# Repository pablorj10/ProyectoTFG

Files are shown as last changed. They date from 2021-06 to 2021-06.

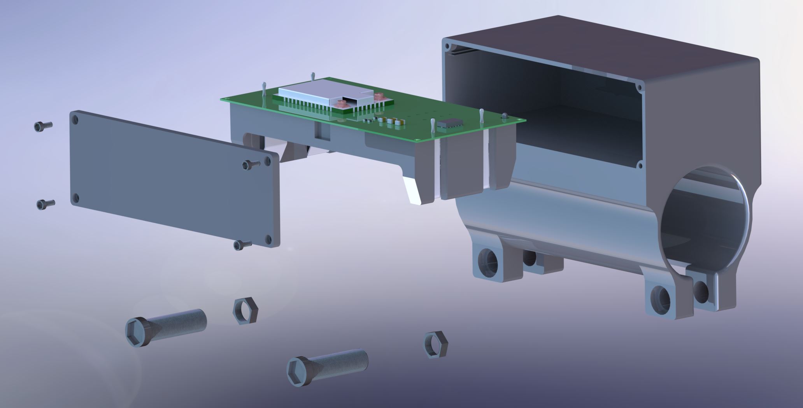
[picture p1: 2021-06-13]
SolidWork/Fotos/Captura2.JPG

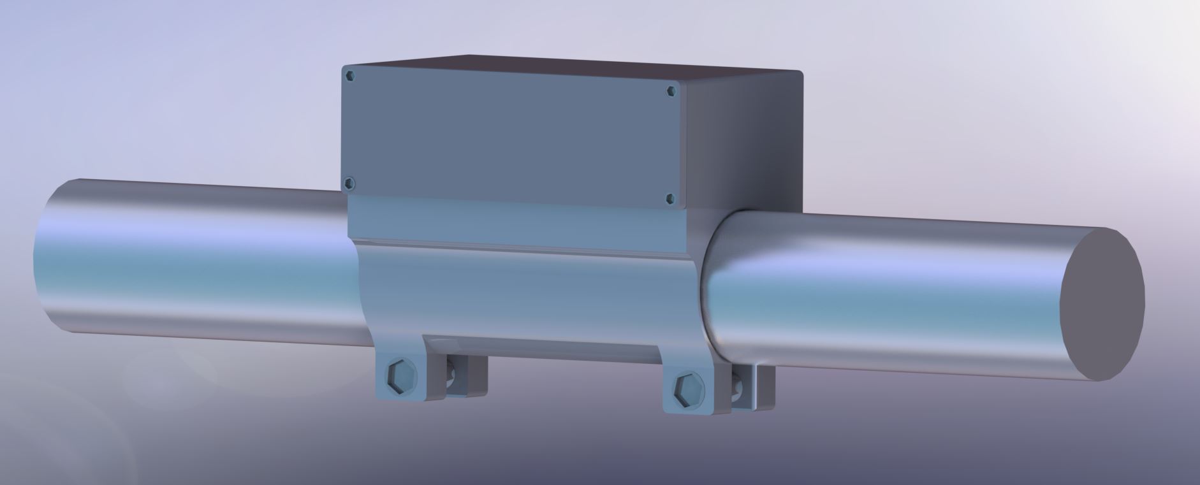
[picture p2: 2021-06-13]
SolidWork/Fotos/Captura3.JPG

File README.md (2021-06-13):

# ProyectoTFG
Repositorio donde se muestran todos los documentos para la elaboración del Trabajo de Fin de Grado de la carrera de Grado en Ingeniería Electrónica Industrial de la Universidad de Granada: Plataforma IoT para el seguimiento de la actividad deportiva en parques biosaludables elaborado por Pablo Rubio Jiménez.

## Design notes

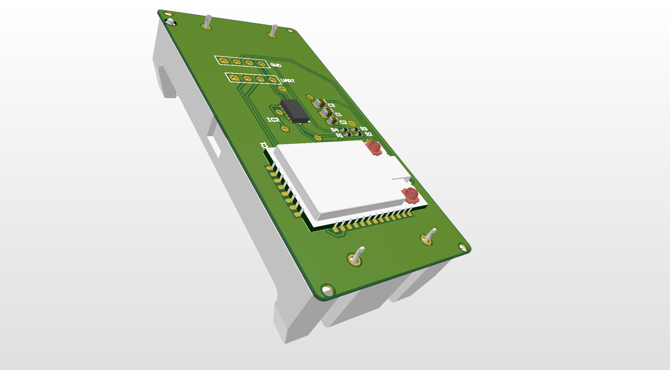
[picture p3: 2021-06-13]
Altium/TFG_Dispositivo/PCB_Dispositivo2.jpg

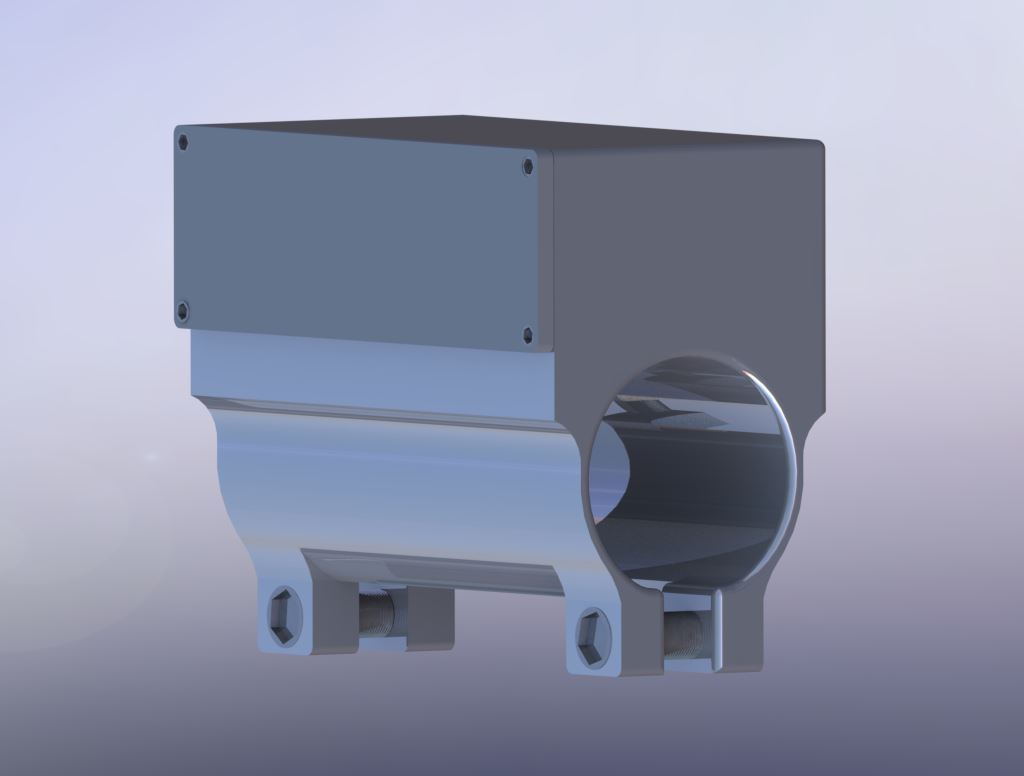
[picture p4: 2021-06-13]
SolidWork/Fotos/Captura1.JPG

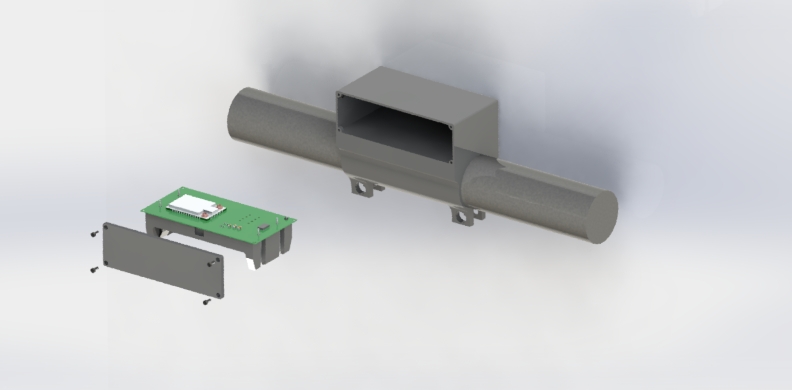
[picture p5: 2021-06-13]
SolidWork/Fotos/preview.JPG

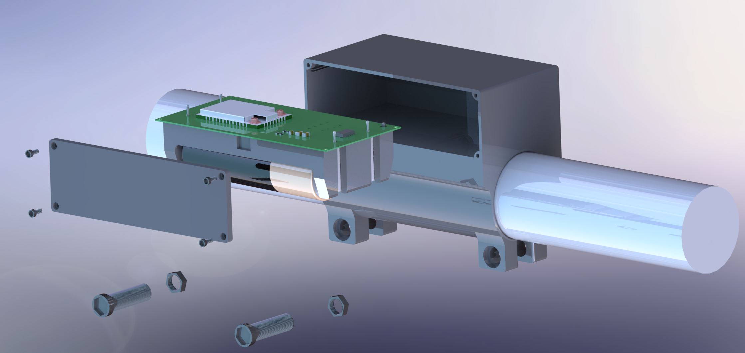
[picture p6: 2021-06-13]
SolidWork/Fotos/Captura5.JPG

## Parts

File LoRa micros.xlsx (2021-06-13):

TECNOLOGÍA LORA
Microcontrolador | Módulo LoRa | Microcontrolador | Medidas | Consumo | Alimentación | Frecuencia de transmisión | Memoria Flash | SRAM | EEPROM | Precio
Bastwan | RAK3244 | SAMD21 Cortex-M0 | 50,8 x 22,8 mm | 123,6 mA Máx. (Transmitiendo Tx), 13,6 mA Máx. (Recibiendo Rx), 860 nA (Sleep Mode) | USB (5V) o batería Li-Po | 862-1020 MHz | 256 KB | 32 KB | No | 29.90 €
MKR1300 Arduino | CMWX1ZZABZ | SAMD21 Cortex-M0 | 67,64 x 25 mm |  | USB (5V) o Baterías 2x AA o AAA | 433/868/915 MHz | 256 KB | 32 KB | No | 24.50 €
MKR1310 Arduino | CMWX1ZZABZ | SAMD21 Cortex-M0 | 67,64 x 25 mm | Consumo Medio de 104 uA | USB (5V) o baterías recargables Li-ion o Li-Po, con mínimo de 1024 mAh de capacidad | 433/868/915 MHz | 256 KB (CPU internal) y 2 MB (QSPI external) | 32 KB | No | 33.00 €
IoT Platzi ESP32 + Lora (Wifi, Bluetooth, LoRa) | SX1276 | ESP32 |  | 29-120 mA (transmitiendo), 0,2 uA (sleep mode),1,5 uA (IDLE) |  | 433/868/915 MHz |  |  |  | 35.00 €
ADAFRUIT FEATHER Mo RFM96/5 LoRa Radio | RFM95 | SAMD21 Cortex-M0 | 50,8 x 23 mm | 120 mA Máx. (Transmitiendo Tx), 40 mA Máx. (Recibiendo Rx), 0,3 mA (Sleep Mode) | USB (5V) o Batería de Polímero de Litio de 3,7V | 433/868/915 MHz | 256 KB | 32 KB | No | 36.95 €
A todos estos consumos, se les debe sumar el consumo propio de los demás elementos de la placa como resistencias, condensadores etc.
CONSUMO Microcontrolador | SAMD21 Cortex-M0
 | Activo |  | IDLE |  | StandBy
 | Min | 3.7 | Min | 1.3 | Min | 0.0034
 | Max | 4.7 | Max | 2.6 | Max | 0.104
 | Módulo LoRa |  |  |  | Simulación del consumo
 | Max. | 120
 | Min. | 70 |  | Horas | Personas | Consumo medio en la hora (mA)
 |  |  |  | 1:00:00 | 0 | 0.104 |  | Datos de las personas y las horas obtenidas del artículo: Chow H-w, Mowen AJ, Wu G-l. Who Is Using Outdoor Fitness Equipment and How? The Case of Xihu Park. International Journal of Environmental Research and Public Health. 2017; 14(4):448. https://doi.org/10.3390/ijerph14040448
 |  |  |  | 2:00:00 | 0 | 0.104
Suponiendo que el módulo de LoRa está activado durante 5 segundos, por cada persona que usa la máquina. El resto del tiempo está apagado. |  |  |  | 3:00:00 | 0 | 0.104
 |  |  |  | 4:00:00 | 0 | 0.104
 |  |  |  | 5:00:00 | 0 | 0.104
 |  |  |  | 6:00:00 | 0 | 0.104
 | Tiempo LoRa por persona (s) | 0 |  | 7:00:00 | 20 | 0.2316666667
 |  |  |  | 8:00:00 | 25 | 0.2635833333 |  | Batería (mAh) | 4000
Suponiendo que el microcontrolador está en modo activo durante 5 segundos, por cada persona que usa la máquina. El resto del tiempo está en modo standby. |  |  |  | 9:00:00 | 16 | 0.2061333333
 |  |  |  | 10:00:00 | 7 | 0.1486833333
 |  |  |  | 11:00:00 | 7 | 0.1486833333 |  | Duración Bateria (Años) | 3.239132827
 |  |  |  | 12:00:00 | 3 | 0.12315 |  | Meses | 38.86959393
 | Tiempo MCU por persona (s) | 5 |  | 13:00:00 | 2 | 0.1167666667 |  | Días | 1166.087818
 |  |  |  | 14:00:00 | 3 | 0.12315
 |  |  |  | 15:00:00 | 9 | 0.16145
 |  |  |  | 16:00:00 | 14 | 0.1933666667
 |  |  |  | 17:00:00 | 16 | 0.2061333333
 |  |  |  | 18:00:00 | 4 | 0.1295333333
 |  |  |  | 19:00:00 | 6 | 0.1423
 |  |  |  | 20:00:00 | 7 | 0.1486833333
 |  |  |  | 21:00:00 | 0 | 0.104
 |  |  |  | 22:00:00 | 0 | 0.104
 |  |  |  | 23:00:00 | 0 | 0.104
 |  |  |  | 0:00:00 | 0 | 0.104
 |  |  |  |  | Consumo Medio (mA) | 0.1409701389

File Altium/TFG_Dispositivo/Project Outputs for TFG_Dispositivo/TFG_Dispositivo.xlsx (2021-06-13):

 | Bill of Materials
 |  |  |  |  |  |  | 2175 Salk Avenue
 | Project Title: | Bill of Materials for BOM Document [TFG_Dispositivo.BomDoc] |  |  |  |  | Suite 200
 | Project File Name: | TFG_Dispositivo.PrjPcb |  |  |  |  | Carlsbad, CA 92008
 | Assembly Variant: | None |  |  |  |  | USA
Part Number | Description | Designator | Manufacture | Manufacture Part Number | Supplier | Supplier Part Number | Supplier Unit Price | Quantity
C0805X104M5RACTU | Capacitor | C1, C3 | KEMET | C0603C104K5RACTU | Digi-Key | 399-5089-1-ND | $0.12 | 2
0603ZD106KAT2A | Capacitor | C2 | KEMET | C1210C106Z4VACTU | Digi-Key | 399-1272-6-ND | $0.57 | 1
RAK4600 | Integrated Circuit | IC1 | RAKWireless | - | RAKWireless | - | $9.70 | 1
ADXL345BCCZ-RL | Integrated Circuit | IC2 | Analog Devices | ADXL345BCCZ-RL7 |  |  |  | 1
Header 4 | Header, 4-Pin | P1, P2 | Wurth Electronics | 61300411121 | Digi-Key | 732-5317-ND | $0.18 | 2
CPF0402B10KE | Resistor | R1, R2, R3, R4 | Vishay | CRCW0603-10K0FKEA | Digi-Key | 541-10.0KHCT-ND | $0.04 | 4
1013 | Undefined or Miscellaneous | U1 | Keystone Electronics | 1013 | Digi-Key | 36-1013-ND | $4.64 | 1
 |  |  |  |  |  |  | $15.25 | 12
Approved |  | Notes

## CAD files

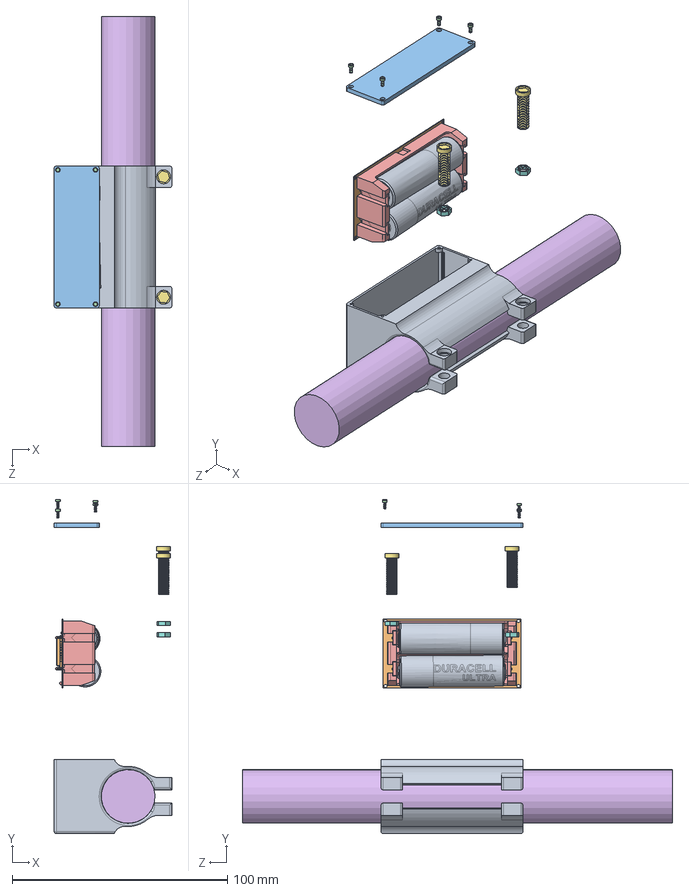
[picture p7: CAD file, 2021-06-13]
SolidWork/ENSAMBLAJE/Ensamblaje.SLDASM
54.8 x 155.4 x 200.0 mm
Pieza_Delantera
PCB_Dispositivo
Pieza_Tapadera
Pieza_Tornillo_Peque x 4
User Library-1013-1
Pieza_tornillo_grande x 2
Pieza_tuerca x 2
User Library-duracell ultra aa 1_5v mx 1500 lr6 x 2

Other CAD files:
Altium/TFG_Dispositivo/Pad RAK4600-23(29.2mm,13.75mm) on Top Layer-1.SLDASM
SolidWork/NetIC2_7.SLDASM
Altium/TFG_Dispositivo/TX.SLDASM
Altium/TFG_Dispositivo/Pad RAK4600-23(29.2mm,13.75mm) on Top Layer.SLDASM
SolidWork/Track (19.975mm,29.725mm)(20.3mm,29.4mm) on Top Layer.SLDASM
SolidWork/Track (22.2mm,53.3mm)(22.2mm,55.903mm) on Top Layer-1.SLDASM
SolidWork/Track (10.2mm,37.8mm)(10.2mm,53.1mm) on Top Layer-1.SLDASM
SolidWork/Pad ADXL345-6(19mm,58.097mm) on Top Layer.SLDASM
SolidWork/Track (18.353mm,49.947mm)(18.353mm,56.749mm) on Top Layer.SLDASM
SolidWork/Pad RAK4600-15(18.725mm,8.691mm) on Top Layer.SLDASM
SolidWork/Track (10.2mm,53.1mm)(17.9mm,60.8mm) on Top Layer.SLDASM
SolidWork/Pad RAK4600-36(24.975mm,31.391mm) on Top Layer.SLDASM
SolidWork/Polygon Region (0 hole(s)) Top Layer-2.SLDASM
SolidWork/Pad C1-2(27.19mm,46mm) on Top Layer-1.SLDASM
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

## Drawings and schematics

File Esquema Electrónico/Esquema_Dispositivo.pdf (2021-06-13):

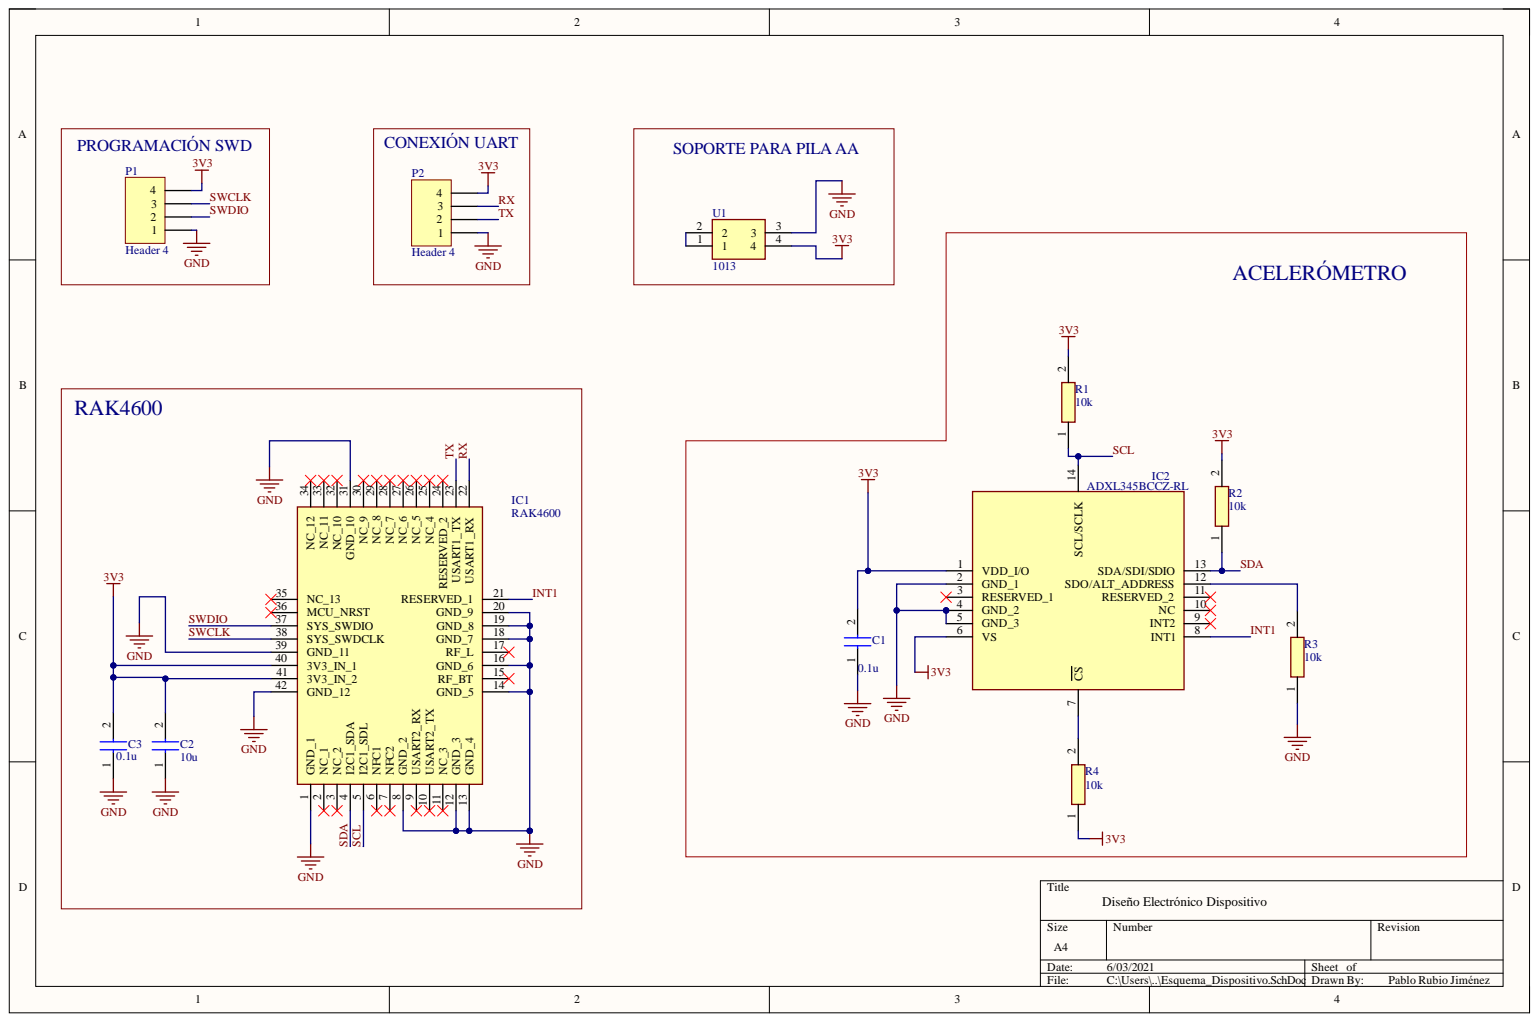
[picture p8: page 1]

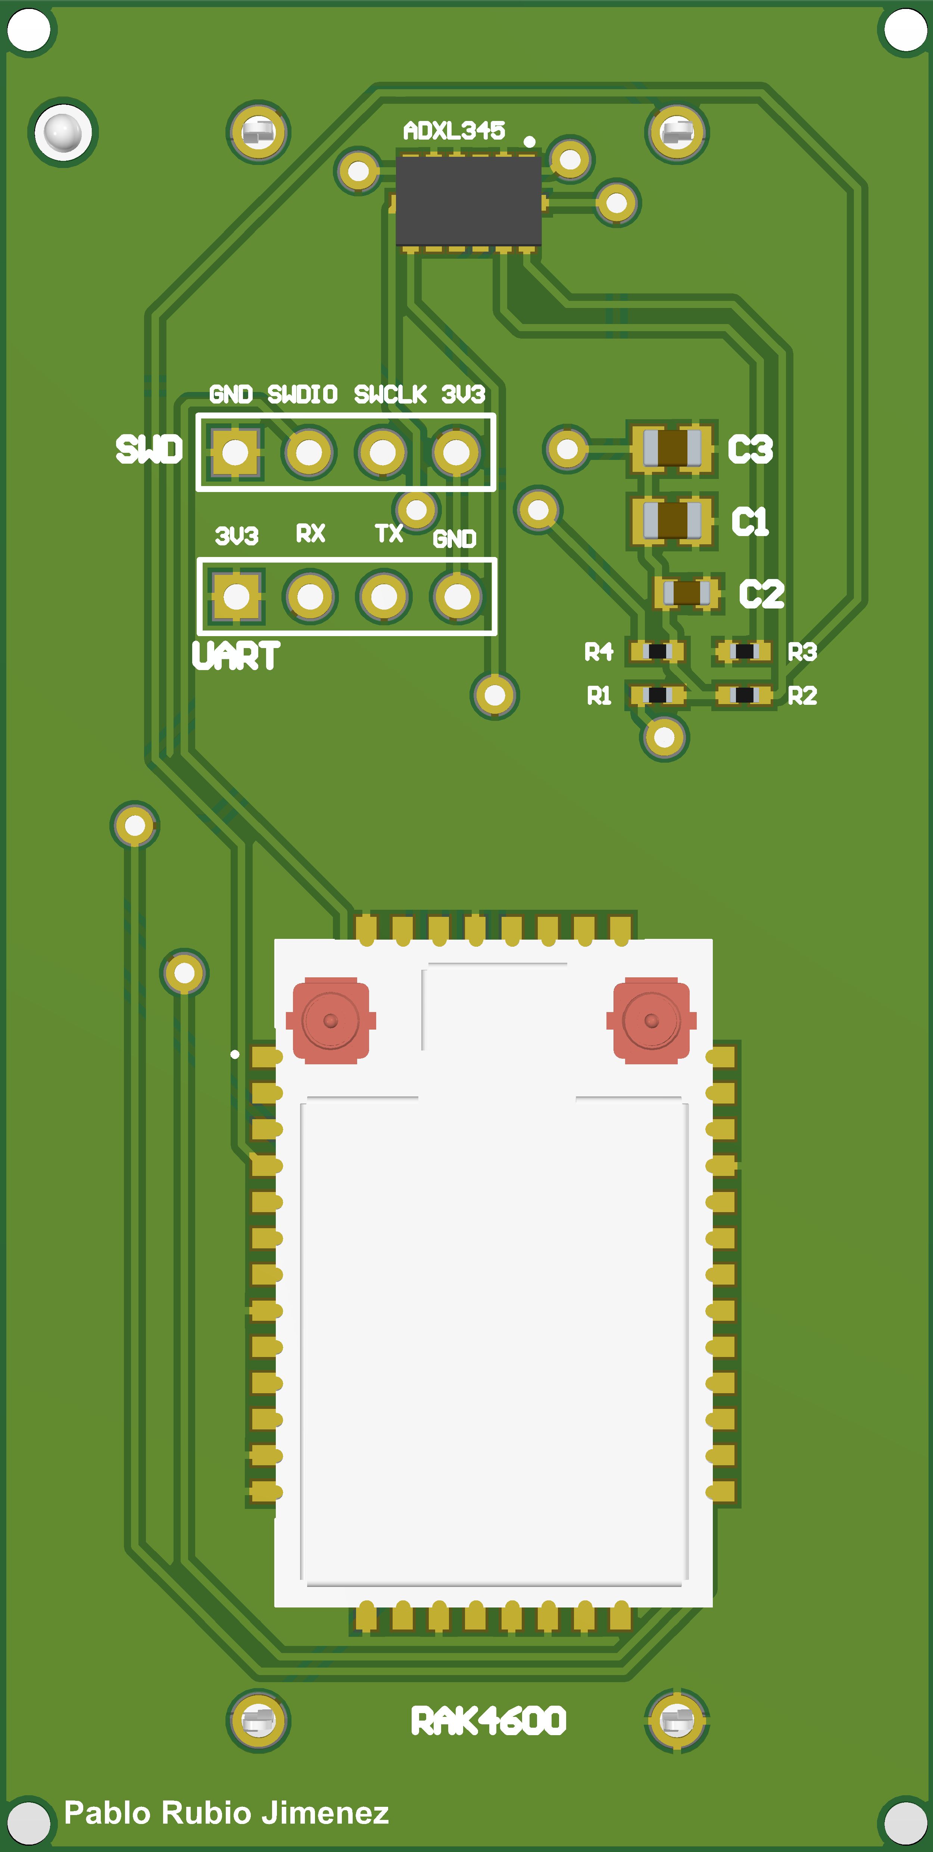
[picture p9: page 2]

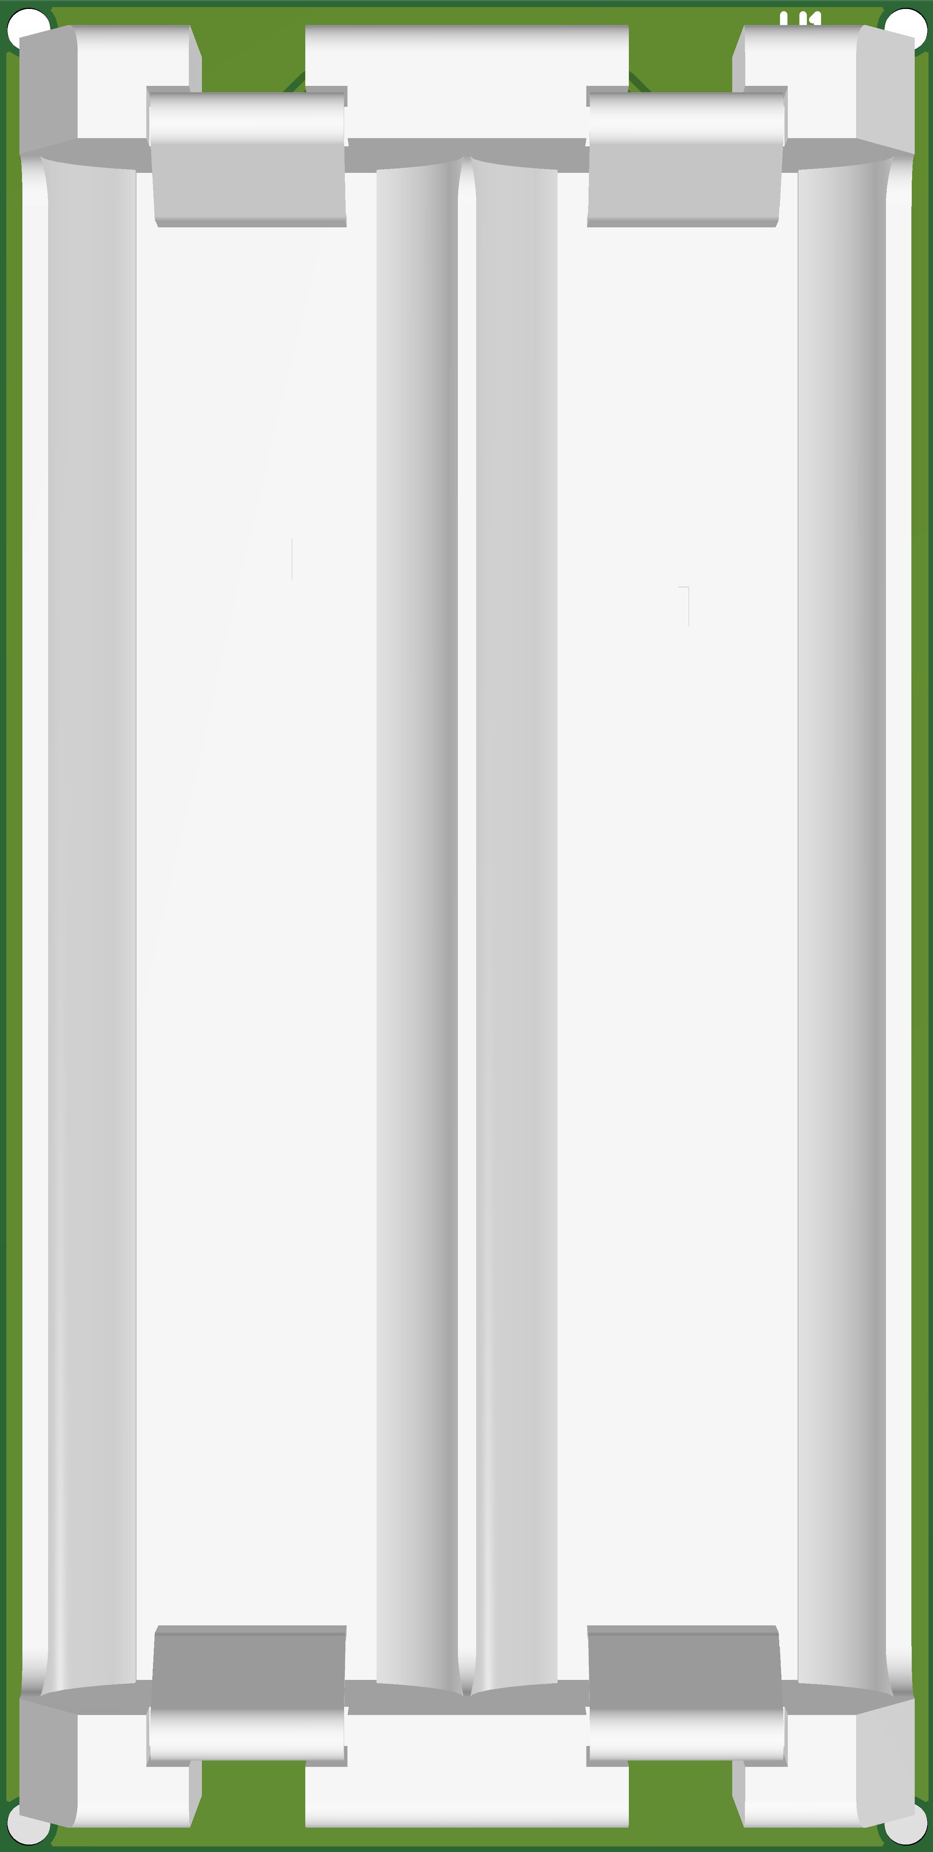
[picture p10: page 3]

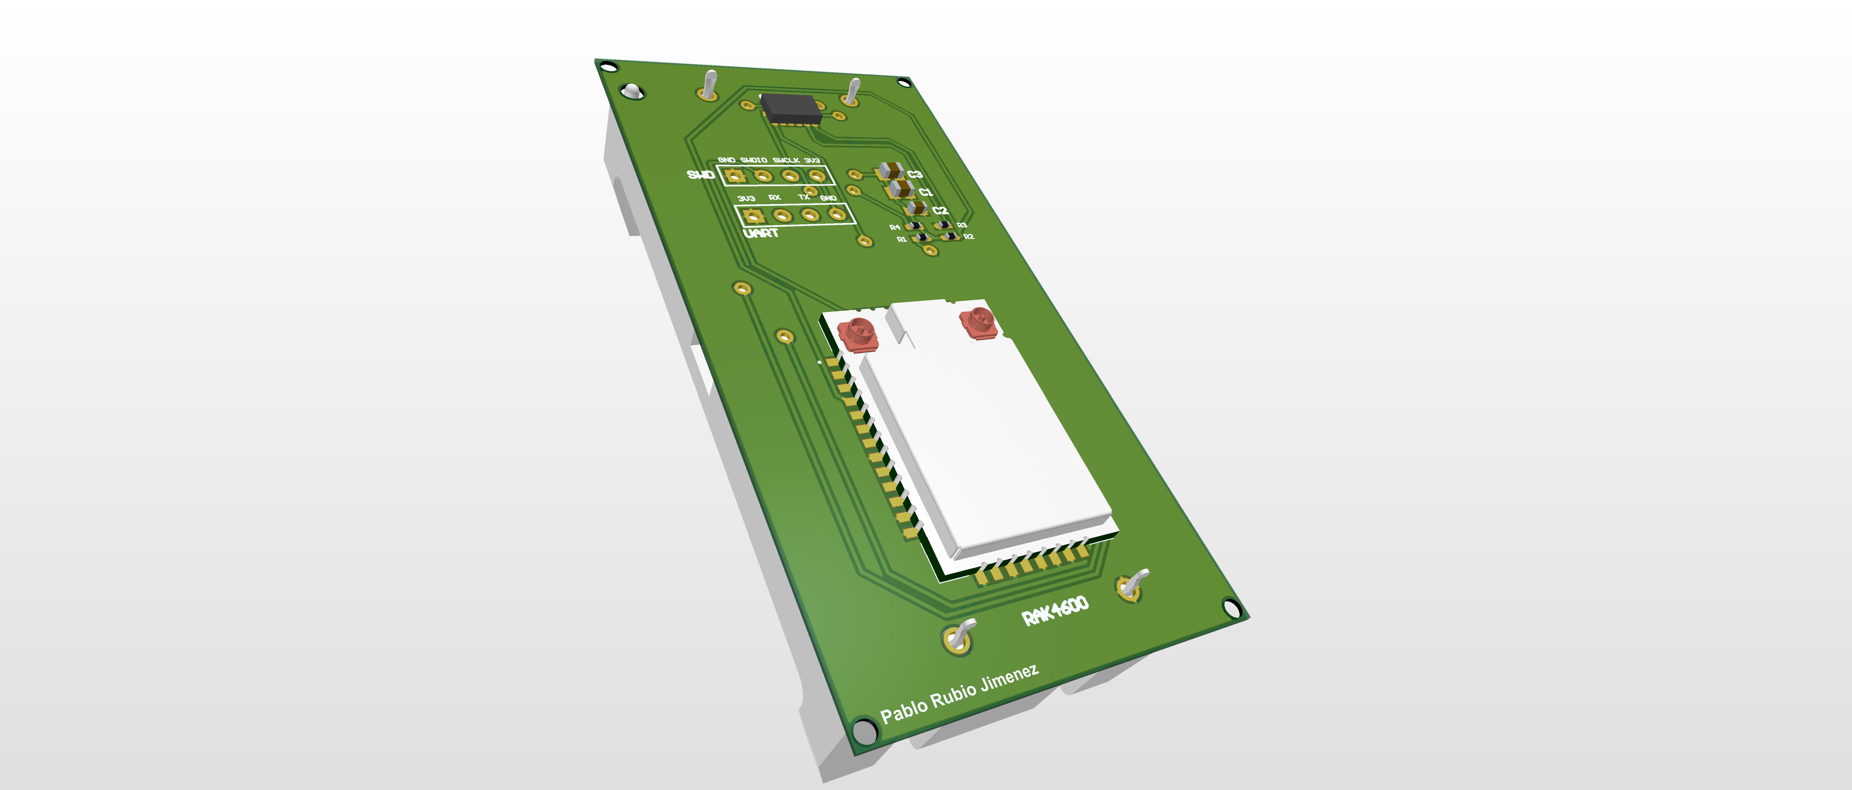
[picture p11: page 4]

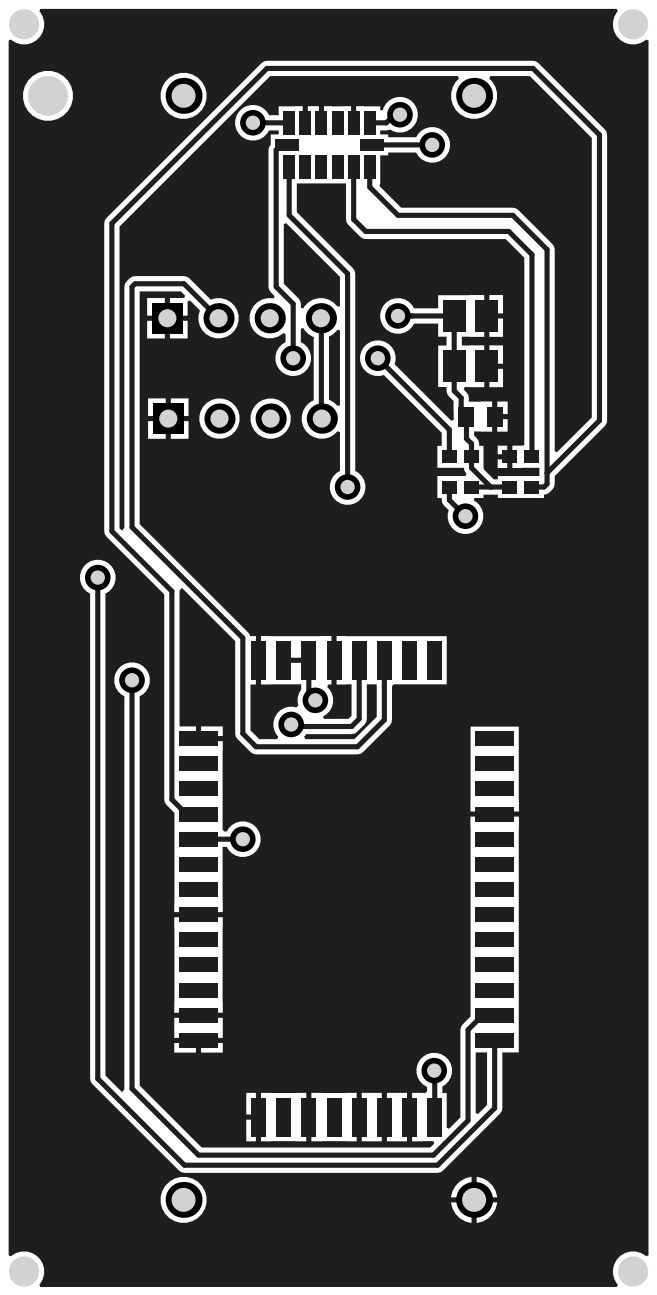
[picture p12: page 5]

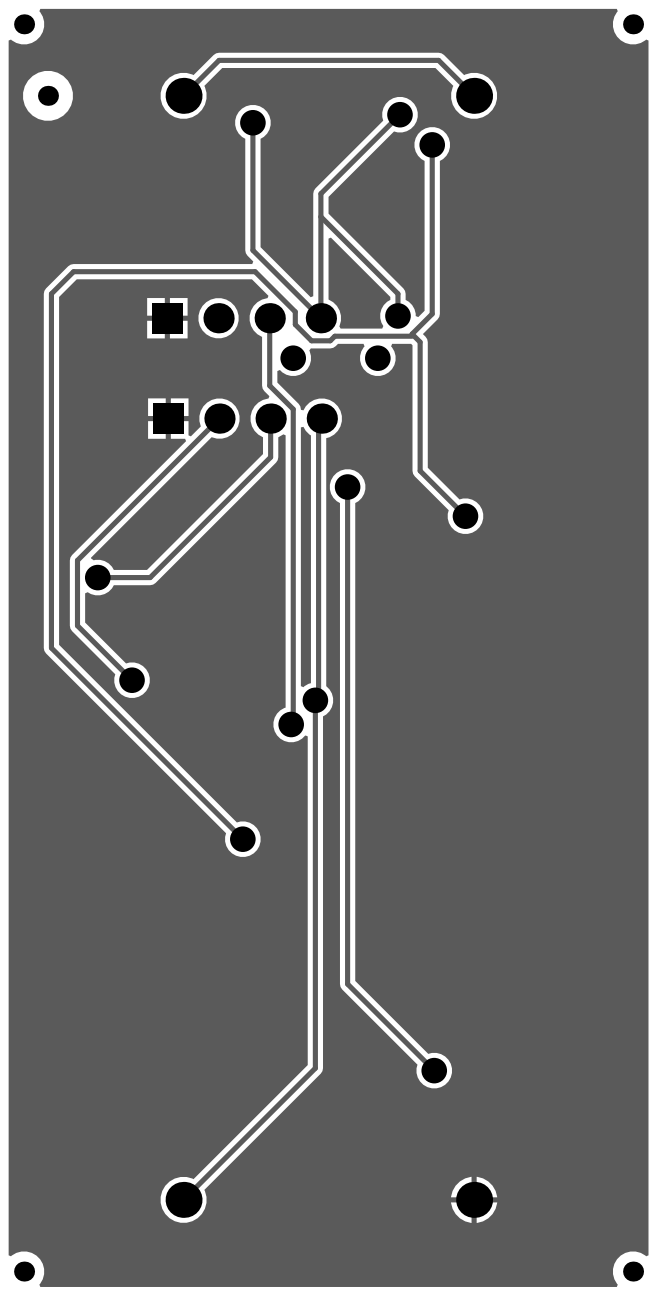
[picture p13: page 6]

# Bill of Materials

### 2175 Salk Avenue

Project Title: Bill of Materials for BOM Document [TFG_Dispositivo.BomDoc] | Suite 200
Project File Name: TFG_Dispositivo.PrjPcb | Carlsbad, CA 92008
Assembly Variant: None | USA
Part Number | Description | Designator | Manufacture | Manufacture Part Number | Supplier | Supplier Part Number | Supplier Unit Price | Quantity
C0805X104M5RACTCapacitor | | C1, C3 | KEMET | C0603C104K5RACTU | Digi-Key | 399-5089-1-ND | $0.12 | 2
0603ZD106KAT2ACapacitor | | C2 | KEMET | C1210C106Z4VACTU | Digi-Key | 399-1272-6-ND | $0.57 | 1
RAK4600 | Integrated Circuit | IC1 | RAKWireless | - | RAKWireless | - | $9.70 | 1
ADXL345BCCZ-RL Integrated Circuit | | IC2 | Analog Devices | ADXL345BCCZ-RL7 | Mouser | 584-ADXL345BCCZ-R7 | $6.23 | 1
Header 4 | Header, 4-Pin | P1, P2 | Wurth Electronics | 61300411121 | Digi-Key | 732-5317-ND | $0.18 | 2
CPF0402B10KE | Resistor | R1, R2, R3, R4 | Vishay | CRCW060310K0FKEA | Digi-Key | 541-10.0KHCT-ND | $0.04 | 4
1013 | Undefined or Miscellaneous | U1 | Keystone Electronics | 1013 | Digi-Key | 36-1013-ND | $4.64 | 1
| $21.48 12
Approved | Notes

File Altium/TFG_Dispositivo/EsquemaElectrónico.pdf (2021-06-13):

# 3V3 3V3 SDA

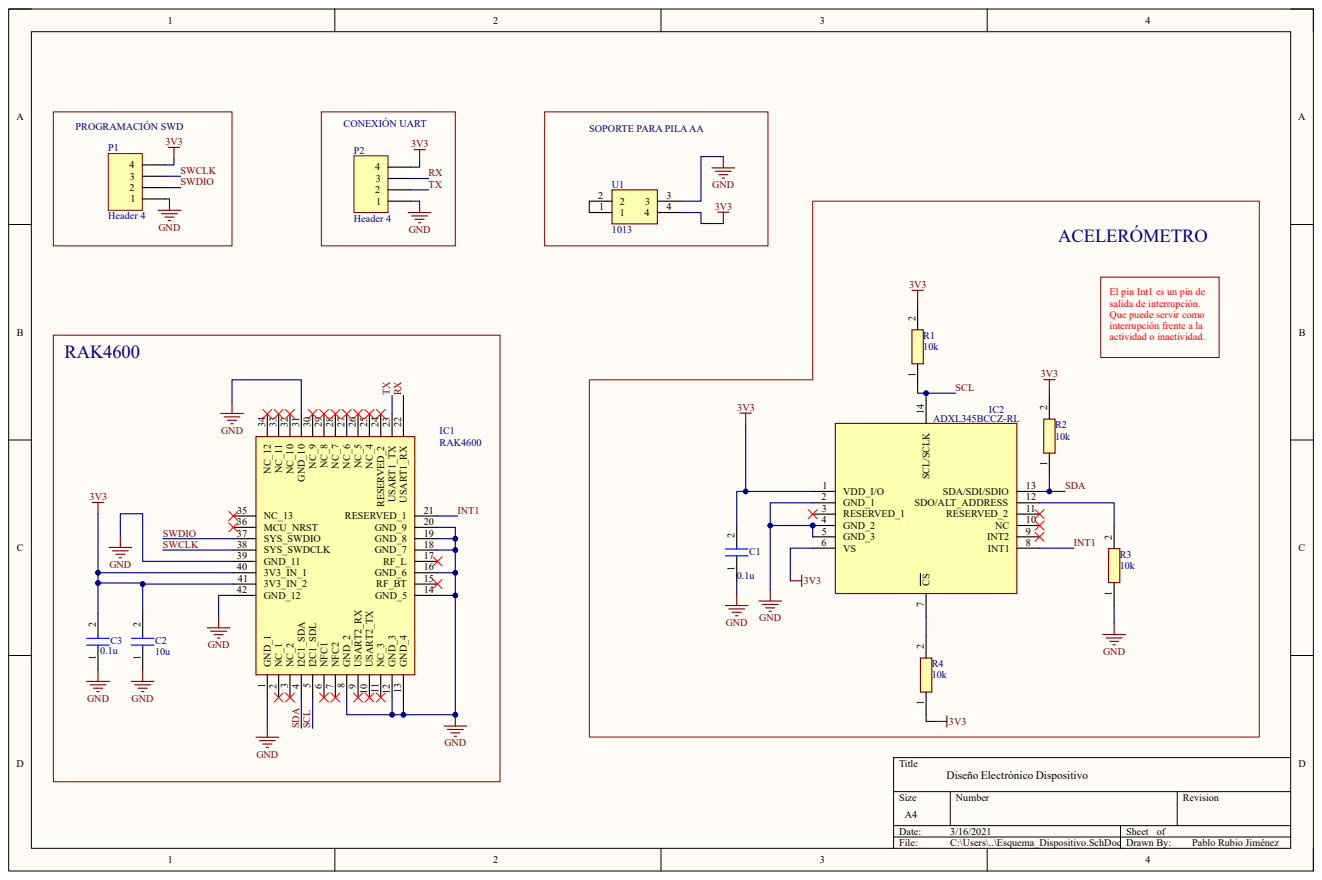
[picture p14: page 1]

SOPORTE PARA PILA AA

El pin Int1 es un pin de
salida de interrupción.
Que puede servir como
interrupción frente a la
actividad o inactividad.

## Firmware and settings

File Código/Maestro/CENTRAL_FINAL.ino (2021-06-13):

//LIBRERIAS
#include<Wire.h>                  
#include<ADXL345_WE.h>           
#include <Arduino.h>             
#include <bluefruit.h>            
#include <Adafruit_LittleFS.h>    
#include <InternalFileSystem.h>   
#include <lmic.h>                
#include <hal/hal.h>              
#include <SPI.h>                 
#include "NRF52TimerInterrupt.h"
#include "NRF52_ISR_Timer.h"
#include <stdlib.h>

/////VARIABLES E INSTANCIAS ///////
#define ADXL345_I2CADDR 0x53                                         
#define TIMER_INTERRUPT_DEBUG                0
#define _TIMERINTERRUPT_LOG_LEVEL_           0
#define PININT1 14
#define PINLED 17
NRF52Timer ITimer0 (NRF_TIMER_1);
NRF52_ISR_Timer  ISR_Timer0;

NRF52Timer ITimer1 (NRF_TIMER_3);
NRF52_ISR_Timer  ISR_Timer1;

ADXL345_WE myAcc(ADXL345_I2CADDR);

unsigned long temporizador_predefinido = 10;
volatile uint32_t temporizador; //SEGUNDOS
volatile uint32_t temporizador_variable;
unsigned long tiempo_reinicio = 30;
volatile uint32_t contador_reinicio = 0;
unsigned long numero_reinicio;
volatile uint8_t tiempo_espera = 20; //Tiempo en el que estara el dispositivo buscando nodos para configurarlos. 
unsigned long tiempo;

volatile uint8_t estado = 1;
typedef struct
{
  char name[16+1];
  uint16_t conn_handle;
  BLEClientUart clientUart;
}prph_info_t;

prph_info_t prphs[3];

volatile bool power = true;
int cont = 0;
volatile int posicion = 0;
uint8_t datos = 0;
unsigned long tiempoinicio;
unsigned long tiempofin;

void registro_dato();


SoftwareTimer blinkTimer;

volatile bool parar_lorawan = false;
volatile bool parar_ble = false;
volatile bool salir_estado5 = false;
volatile bool salir_ble1 = false;
volatile bool salir_lorawan1 = false;
volatile bool reinicio = false;





String datoscentral = "Central";
char datos1[100];
char datos2[100];
char datos3[100];
char datos4[100];
volatile uint8_t contador = 0;

volatile uint8_t tiempo_inactividad = 4;
static const u1_t PROGMEM APPEUI[8]={0x3F,0x19,0x04,0xD0,0x7E,0xD5,0xB3,0x70};
void os_getArtEui (u1_t* buf) { memcpy_P(buf, APPEUI, 8);}

// This should also be in little endian format, see above.
static const u1_t PROGMEM DEVEUI[8]={0x3E,0x4A,0x75,0xFE,0xFF,0xA8,0xC5,0x60};
void os_getDevEui (u1_t* buf) { memcpy_P(buf, DEVEUI, 8);}

// This key should be in big endian format (or, since it is not really a
// number but a block of memory, endianness does not really apply). In
// practice, a key taken from ttnctl can be copied as-is.
static const u1_t PROGMEM APPKEY[16] = { 0xDC,0x20,0x25,0xE8,0xCA,0xD9,0x0E,0x4A,0xF7,0x96,0xB0,0x9E,0xC1,0x82,0x38,0x0E };
void os_getDevKey (u1_t* buf) {  memcpy_P(buf, APPKEY, 16);}

volatile uint32_t lora_count = 0;
static osjob_t sendjob;
char Datos_conf[50] = "Configuracion";

uint8_t N = 10;
int Q;

volatile uint8_t cont1 = 0;
volatile uint8_t variable = 0;
typedef enum {
  LORA_UNCONFIRMED,
  LORA_CONFIRMED  
};

const unsigned TX_INTERVAL = 10;

const lmic_pinmap lmic_pins = {
    .nss = 4,
    .rxtx = LMIC_UNUSED_PIN,
    .rst = LMIC_UNUSED_PIN,
    .dio = {27, 28, 29},
};









////////////////////////////////////////////////////////////////////////////////////////////////////////////////////////////////////////////////////////
////////////////////////////////////////////////////////////VARIABLE DINAMICOS////////////////////////////////////////////////////////////////////////
///////////////////////////////////////////////////////////////////////////////////////////////////////////////////////////////////////////////////////

int* datostiempo;
size_t counta;
size_t capacity;


void reinicio_datos()
{
  Serial.println("Valores reiniciados");
  datoscentral = "";
  datoscentral = "Central";
  datos = 0;
  cont = 0;
  posicion = 0;
  memset(datos2, 0, sizeof(datos2));
}

void convertir_datos()
{
  Serial.println("Datos convertidos");
  int datos_len = datoscentral.length() + 1;
  datoscentral.toCharArray(datos1, 100);
}


void CreateList(size_t _capacity)
{
  datostiempo = new int[_capacity];
  capacity = _capacity;
  counta = 0;
}

void AddItem(int item)
{
  ++counta;
  if(counta> capacity)
  {
    size_t newSize = capacity*2;
    resize(newSize);
  }
  datostiempo[counta -1] = item;
}
void RemoveTail()
{
  --counta;
}

void Trim()
{
  resize(counta);
  
}

void resize(size_t newCapacity)
{
  int* newList = new int[newCapacity];
  memmove(newList, datostiempo, counta * sizeof(int));
  delete[] datostiempo;
  capacity = newCapacity;
  datostiempo = newList;
}

void PrintList()
{
  Serial.print("Datos Tiempos: ");
  for (size_t index = 0; index < counta; index++)
  {
    Serial.print(datostiempo[index]);
    Serial.print(' ');
  }
  Serial.println();

}


/////////////////////////////////////////////////////////////////////////////////////////////////////////////////////////////////////////
/////////////////////////////////////////////////////////////TEMPORIZADOR///////////////////////////////////////////////////////////////////
///////////////////////////////////////////////////////////////////////////////////////////////////////////////////////////////////////////



void funcion_tempo(TimerHandle_t xTimerID)
{
    (void) xTimerID;
    Serial.println("TIEMPO----------------------------");
    salir_estado5 = true;
    estado = 6;
    Serial.println("Parar temporizador");
  
}
void tiempo_de_espera()
{
  parar_ble = true;
  estado = 3;
}
void temporizador_handler()
{
  if(estado == 2)
  {
    ISR_Timer1.run();
    ISR_Timer1.setTimeout(tiempo_espera*1000, tiempo_de_espera);
  }
  if(estado == 4)
  {
    
    //ISR_Timer0.run();
    //ISR_Timer0.setTimeout(tiempo_reinicio*1000, funcion_tempo);

  }
}



////////////////////////////////////////////////////////////////////////////////////////////////////////////////////////////////////////////////////
////////////////////////////////////////////////LORAWAN/////////////////////////////////////////////////////////////////////////////////////////////
////////////////////////////////////////////////////////////////////////////////////////////////////////////////////////////////////////////////////////
void apagar_lorawan()
{
  os_clearCallback(&sendjob);
  LMIC_shutdown();
  Serial.println("LoRaWAN apagado");
  parar_lorawan = true;
  if(estado == 1){estado = 2;}
  if(estado == 7){estado = 8; salir_lorawan1 = true;}
}




void envio_lorawan_conf(osjob_t* j)
{
  if(LMIC.opmode & OP_TXRXPEND)
  {
    Serial.println(F("OP_TXRXPEND, not sending"));
  }
  else
  {
    LMIC_setTxData2(1, (unsigned char *) Datos_conf, strlen(Datos_conf), LORA_CONFIRMED);
    Serial.println("Dato enviado a LoRaWAN");
    contador++;
    
    if(contador == 5 && temporizador == 0)
    {
      Serial.println("No se ha establecido conexión con LoRaWAN");
      Serial.println("Se establece el temporizador predeterminado de 400 segundos");
      temporizador = temporizador_predefinido;
      apagar_lorawan();
    }
  }
}

void envio_lorawan_datos(osjob_t* j)
{
  switch(variable)
  {
    case 0:
    Serial.println("CASO 0");
    convertir_datos();
    if(strlen(datos1) > 1)
    {
      Serial.println("Datos1 hay datos");
      LMIC_setTxData2(1, (unsigned char *)datos1, strlen(datos1), LORA_CONFIRMED);
      Serial.println(F("Paquete enviado 1"));
      variable++;
    }
    else
    {
      Serial.println("No hay datos1");
      variable = 0;
    }
    break;

    case 1:
    Serial.println("CASO 1");
    if(strlen(datos2) > 1 && *datos2 != '0')
    {
      LMIC_setTxData2(1, (unsigned char *)datos2, strlen(datos2), LORA_CONFIRMED);
      Serial.println(F("Paquete enviado 2"));
      variable++;
    }
    else
    {
      Serial.println("No hay más datos para enviar por LoRaWAN");
      variable = 0;
      apagar_lorawan();
      break;
    }
    break;

    case 2:

    Serial.println("CASO 2");
    if(strlen(datos3) > 1 && *datos3 != '0')
    {
      LMIC_setTxData2(1, (unsigned char *)datos3, strlen(datos3), LORA_CONFIRMED);
      Serial.println(F("Paquete enviado 3"));
      variable++;
    }
    else
    {
      Serial.println("No hay más datos para enviar por LoRaWAN");
      variable = 0;
      apagar_lorawan();
      break;
    }
    break;

    case 3:

    Serial.println("CASO 3");
    if(strlen(datos4) > 1 && *datos4 != '0')
    {
      LMIC_setTxData2(1, (unsigned char *)datos4, strlen(datos4), LORA_CONFIRMED);
      Serial.println(F("Paquete enviado 4"));
      variable = 0;
    }
    else
    {
      Serial.println("No hay más datos para enviar por LoRaWAN");
      variable = 0;
      apagar_lorawan();
      break;
    }
    break;
  }
  
}






void onEvent (ev_t ev) {
    //Serial.print(os_getTime());
    //Serial.print(": ");
    switch(ev) {
        case EV_SCAN_TIMEOUT:
            Serial.println(F("EV_SCAN_TIMEOUT"));
            break;
        case EV_BEACON_FOUND:
            Serial.println(F("EV_BEACON_FOUND"));
            break;
        case EV_BEACON_MISSED:
            Serial.println(F("EV_BEACON_MISSED"));
            break;
        case EV_BEACON_TRACKED:
            Serial.println(F("EV_BEACON_TRACKED"));
            break;
        case EV_JOINING:
            //Serial.println(F("EV_JOINING"));
            Serial.println(F("Comenzando a Unirse..."));
            break;
        case EV_JOINED:
            Serial.println(F("Enlazado con LoraWAN"));
            {
              u4_t netid = 0;
              devaddr_t devaddr = 0;
              u1_t nwkKey[16];
              u1_t artKey[16];
              LMIC_getSessionKeys(&netid, &devaddr, nwkKey, artKey);
              Serial.println("Unido a LoraWAN");
              Serial.print("netid: ");
              Serial.println(netid, DEC);
              Serial.print("devaddr: ");
              Serial.println(devaddr, HEX);
              Serial.print("artKey: ");
              for (size_t i=0; i<sizeof(artKey); ++i) {
                Serial.print(artKey[i], HEX);
              }
              Serial.println("");
              Serial.print("nwkKey: ");
              for (size_t i=0; i<sizeof(nwkKey); ++i) {
                Serial.print(nwkKey[i], HEX);
              }
              Serial.println("");

              lora_count = 1;
            }

            LMIC_setLinkCheckMode(0);
            break;

        case EV_JOIN_FAILED:
            Serial.println(F("EV_JOIN_FAILED"));
            break;
        case EV_REJOIN_FAILED:
            Serial.println(F("EV_REJOIN_FAILED"));
            break;
        case EV_TXCOMPLETE:

            if(estado == 1)
            {
              if (LMIC.dataLen == 1) 
              {
                temporizador = LMIC.frame[LMIC.dataBeg + 0];
                Serial.println("Dato de temporizador recibido");
                Serial.print("Tiempo de temporizador: "); 
                Serial.println(temporizador);
                
                apagar_lorawan();
                break;
              } 
            }  
            else
            { 
              
              if (LMIC.txrxFlags & TXRX_ACK)
              {
              Serial.println(F("Recibida Confirmacion \r\n"));
              }
    
              if (LMIC.dataLen) 
              {
                Serial.print(F("Received "));
                Serial.print(LMIC.dataLen);
                Serial.println(F(" bytes of payload"));
              
              }                                         
            }
            
            break;
        case EV_LOST_TSYNC:
            Serial.println(F("EV_LOST_TSYNC"));
            break;
        case EV_RESET:
            Serial.println(F("EV_RESET"));
            break;
        case EV_RXCOMPLETE:
            
            Serial.println(F("EV_RXCOMPLETE"));
            break;
        case EV_LINK_DEAD:
            Serial.println(F("EV_LINK_DEAD"));
            break;
        case EV_LINK_ALIVE:
            Serial.println(F("EV_LINK_ALIVE"));
            break;

        case EV_TXSTART:
        
            if(estado == 1)
            {
              os_setTimedCallback(&sendjob, os_getTime()+sec2osticks(TX_INTERVAL), envio_lorawan_conf);
            }
            if(estado == 7)
            {
              os_setTimedCallback(&sendjob, os_getTime()+sec2osticks(TX_INTERVAL), envio_lorawan_datos);
            }
            break;
        default:
            Serial.print(F("Unknown event: "));
            Serial.println((unsigned) ev);
            break;
    }
}




void lorawan_conf()
{
  os_init();
  LMIC_reset();
  if(estado == 1){envio_lorawan_conf(&sendjob);}
  if(estado == 7){envio_lorawan_datos(&sendjob);}
  while(1)
  {
    if(parar_lorawan == true) {break;}
    os_runloop_once();
  }
  
  
}



//////////////////////////////////////////////////////////////////////////////////////////////////////////////////////////////////////////////////
////////////////////////////////////////////////////////////////BLUETOOTH///////////////////////////////////////////////////////////////////////////
////////////////////////////////////////////////////////////////////////////////////////////////////////////////////////////////////////////////////
 void scan_callback(ble_gap_evt_adv_report_t* report)
 {
  Serial.println("Detectado dispositivo");
  Serial.println("Conectando...");
  Bluefruit.Central.connect(report);
 }

int findConnHandle(uint16_t conn_handle)
{
   for(int id=0; id<3; id++)
  {
    if (conn_handle == prphs[id].conn_handle)
    {
      return id;
    }
  }

  return -1;  
}

void conexion_callback(uint16_t conne_handle)
{
  int id = findConnHandle(BLE_CONN_HANDLE_INVALID);
  if(id < 0)return;
  prph_info_t* peer = &prphs[id];
  peer->conn_handle = conne_handle;
  Bluefruit.Connection(conne_handle)->getPeerName(peer->name, sizeof(peer->name)-1);
  Serial.print("Conectado a ");
  Serial.println(peer->name);
  if(prphs[id].clientUart.discover(conne_handle))
  {
    prphs[id].clientUart.enableTXD();
    Bluefruit.Scanner.resume();
  }
  else
  {
    Bluefruit.disconnect(conne_handle);
  }
  
}

void desconexion_callback(uint16_t conn_handle, uint8_t reason)
{
  (void) conn_handle;
  (void) reason;
  int id = findConnHandle(conn_handle);
  if(id<0) return;
  prphs[id].conn_handle = BLE_CONN_HANDLE_INVALID;
  Serial.print(prphs[id].name);
  Serial.println(" desconectado");
}

void bleuart_rx_callback(BLEClientUart& uart_svc)
{
  if(estado == 6)
  {
    Serial.println("Recibiendo dato por BLE");
    while(uart_svc.available())
    {
      Serial.println("");
      Serial.print("Dato recibido: ");
      if(uart_svc.read(datos2, sizeof(datos2)-1))
      {
        Serial.println(datos2);
      
      }
      if(strlen(datos2) > 1)
      {
        estado = 7;
        salir_ble1 = true;
        break;
      }
    }
  }
}

 void config_ble()
 {
  Bluefruit.begin(0,3);
  Bluefruit.setTxPower(4);
  Bluefruit.setName("Dispositivo Central");
  for (uint8_t idx=0; idx<3;idx++)
  {
    prphs[idx].conn_handle = BLE_CONN_HANDLE_INVALID;
    prphs[idx].clientUart.begin();
    prphs[idx].clientUart.setRxCallback(bleuart_rx_callback);
    
  }
  Bluefruit.Central.setConnectCallback(conexion_callback);
  Bluefruit.Central.setDisconnectCallback(desconexion_callback);
  Bluefruit.Scanner.setRxCallback(scan_callback);
  Bluefruit.Scanner.restartOnDisconnect(false);
  Bluefruit.Scanner.filterUuid(BLEUART_UUID_SERVICE);
  Bluefruit.Scanner.setInterval(160, 80);
  Bluefruit.Scanner.useActiveScan(false);
  Serial.println("BLE Configurado");
  if (estado == 2)
  {
    Serial.println("Comienzo de conexión con nodos");
    ITimer1.attachInterruptInterval(tiempo_espera*1000, temporizador_handler);
    
  }
  Bluefruit.Scanner.start(20000);
  Serial.println("Escaneando....");
  
 }
 
 void sendAll(uint32_t buf)
 {
  Serial.print("Enviando a todos los nodos: ");
  Serial.println(buf);
  for(uint8_t id=0; id<3 ;id++)
  {
    prph_info_t* peer = &prphs[id];
    if (peer->clientUart.discovered())
    {
      delay(1000);
      peer->clientUart.write(buf);
    }
  }
 }


void desconexion_ble()
{
  for(uint8_t id = 0; id<3; id++)
  {
    uint16_t conn_handle = prphs[id].clientUart.connHandle();
    Bluefruit.disconnect(conn_handle);
  }
}
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
void loop()
{
  switch(estado)
  {


    //---------------------------------------------------------------------------------------------------
    //Estado de configuración en el que se conecta con lorawan y se recibe el tiempo del temporizador. 
    case 1:

    Serial.println("Configurando dispositivo");
    Serial.println("A la espera de conexión con LoRaWAN...");
    lorawan_conf();
    
    break;



    //--------------------------------------------------------------------------------------------------
    //Estado de configuracion en el que se configura el bluetooth y se comienza a escanear nodos
    case 2:

    Serial.println("Configurando los demás nodos....");

    config_ble();
    while(1)
    {
      if(parar_ble == true){break;}
      sd_app_evt_wait();
      
    }
    parar_ble = false;
    break;
    //------------------------------------------------------------------------------------------------
    //Estado de configuracion en el que se envía el tiempo a todos los nodos conectados.
    case 3:
    ITimer1.stopTimer();
    Serial.println("Tiempo de escaneo superado");
    Serial.println("Enviando datos a los nodos conectados");
    sendAll(temporizador);
    desconexion_ble();
    uint8_t conexiones;
    
     
     while(1)
     {
      for(uint8_t id = 0; id<3; id++)
      {
        uint16_t conn_handle = prphs[id].clientUart.connHandle();
        if(Bluefruit.connected(conn_handle) == true)
        {
          conexiones++;
        }
        
      }
     
      if(conexiones == 0)
      {
        estado = 4;
        break;
      }
      else
      {
        desconexion_ble();
        
      }
     }
    
    break;

    //-----------------------------------------------------------------------------------------------------
    //Estado en el que se configura el temporizador con el tiempo recibido por LoRaWAN y se configura
    //también el acelerómetro.
    case 4:
    temporizador_variable = temporizador;
    numero_reinicio = tiempo_reinicio/temporizador_variable;
    Serial.print("Temporizador variable: ");
    Serial.println(temporizador_variable);
    //ITimer0.attachInterruptInterval(temporizador_variable*1000000, temporizador_handler);
    //ITimer2.attachInterruptInterval(temporizador_variable*1000000, temporizador_handler);
    temporizador_variable = temporizador;
    blinkTimer.begin(temporizador_variable*1000*60, funcion_tempo, NULL, false);
    blinkTimer.start();
    Serial.println("Temporizador iniciado");
    conf_acelerometro();
    estado = 5;
   
    break;

    //---------------------------------------------------------------------------------------------------------
    //Estado en de normalidad de bajo consumo en el que se está registrando datos hasta que salta el temporizador
    //y se sale de este estado al estado de recepción de los datos de los nodos. 
    case 5:

    while(1)
    {
      if(salir_estado5 == true){break;}
      sd_app_evt_wait();
    
    
    }
    salir_estado5 = false;
    break;

    //-------------------------------------------------------------------------------------------------------------
    //Estado en el que se configura el bluetooth para recibir los datos de los nodos, se conecta a los nodos 
    // y se reciben los datos. 
    case 6:

    Serial.println("Final de toma de datos");
    Serial.println("Configurando BLE");
    //ITimer0.stopTimer();
    blinkTimer.stop();
    config_ble();
    while(1)
    {
      if(salir_ble1 == true){break;}
      sd_app_evt_wait();
      
    }
    salir_ble1 = false;
    break;

    //----------------------------------------------------------------------------------------------------------------
    //Estado en el que se envían los datos recibidos por LoRaWAN
    case 7:
    Serial.println("Enviando datos a LoRaWAN...");
    parar_lorawan = false;
    lorawan_conf();
    while(1)
    {
      if(salir_lorawan1 == true){break;}
      sd_app_evt_wait();
      
      
    }
    salir_lorawan1 = false;
    break;

    //----------------------------------------------------------------------------------------------------------------
    //Estado en el que se desconectan todos los nodos.
    case 8:

     Serial.println("Desconectando todos los nodos....");
     desconexion_ble();
     conexiones = 0;
     while(1)
     {
      for(uint8_t id = 0; id<3; id++)
      {
        uint16_t conn_handle = prphs[id].clientUart.connHandle();
        if(Bluefruit.connected(conn_handle) == true)
        {
          conexiones++;
        }
        
        
      }
      
      if(conexiones == 0)
      {
        estado = 9;
        break;
      }
      else
      {
        desconexion_ble();
        
      }
     }
    
     break;

     //-----------------------------------------------------------------------------------------
     //Estado en el que se reinician todos los valores de las variables y el temporizador. 
     case 9: 

     contador_reinicio++;
     reinicio_datos();
     //ISR_Timer0.run();
     //ISR_Timer0.setTimeout(temporizador_variable*1000, funcion_tempo);
     
     
     blinkTimer.reset();
     //blinkTimer.begin(temporizador*1000, funcion_tempo);
     blinkTimer.begin(temporizador_variable*1000*60, funcion_tempo, NULL, false);
     blinkTimer.start();
     
     estado = 5;
     if(contador_reinicio == numero_reinicio){estado = 10;}
     break;
//----------------------------------------------------------------------------------------------------------------------
     //Estado en el que se reinicia el dispositivo para comenzar una nueva configuración.
     case 10:
     Serial.println("REINICIO");
     Serial.println("--------------------------------------------------------------------------------------------");
     NVIC_SystemReset();
     break;
     





  }


}

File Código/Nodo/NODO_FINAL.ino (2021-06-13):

////////////LIBRERIAS, VARIABLES E INSTANCIAS///////////////
#include<Wire.h>
#include<ADXL345_WE.h>
#include <Arduino.h>
#include <bluefruit.h>
#include <Adafruit_LittleFS.h>
#include <InternalFileSystem.h>
#include "NRF52TimerInterrupt.h"
#include "NRF52_ISR_Timer.h"
#include <stdlib.h>
#define TIMER_INTERRUPT_DEBUG                0
#define _TIMERINTERRUPT_LOG_LEVEL_           0
#define ADXL345_I2CADDR 0x53 // 0x1D if SDO = HIGH
#define PININT1 14
//#define PINLED 17

ADXL345_WE myAcc(ADXL345_I2CADDR);
BLEUart bleuart;
NRF52Timer ITimer0 (NRF_TIMER_1);

SoftwareTimer blinkTimer;
volatile uint8_t datos = 0;
void registro_dato();

volatile bool salir_ble = false;
volatile bool salir_recibirdato = false;
volatile bool salir_estado4 = false;
volatile bool salir_ble1 = false;
volatile bool salir_desconexion = false;


volatile uint8_t estado = 1;
volatile uint32_t temporizador;
uint32_t  tiempo_reinicio = 30;
volatile uint32_t contador_reinicio = 0;
volatile uint32_t numero_reinicio;
unsigned long tiempoinicio;
unsigned long tiempofin;
unsigned long tiempo;
uint8_t tiempo_inactividad = 5;



String datos1 = "Nodo1";
char datos2[100];




////////////////////////////////////////////////////////////////////////////////////////////////////////////////////////////////////////////////////////
////////////////////////////////////////////////////////////VARIABLE DINAMICOS////////////////////////////////////////////////////////////////////////
///////////////////////////////////////////////////////////////////////////////////////////////////////////////////////////////////////////////////////

int* datostiempo;
size_t counta;
size_t capacity;


void reinicio_datos()
{
  datos1 = "";
  datos1 = "Nodo1";
  datos2[0] = '\0';
  datos = 0;
  Serial.println("Datos reiniciados");
}

void convertir_datos()
{
  int datos_len = datos1.length() + 1;
  datos1.toCharArray(datos2, 100);
  Serial.println("Datos convertidos");
}


void CreateList(size_t _capacity)
{
  datostiempo = new int[_capacity];
  capacity = _capacity;
  counta = 0;
}

void AddItem(int item)
{
  ++counta;
  if(counta> capacity)
  {
    size_t newSize = capacity*2;
    resize(newSize);
  }
  datostiempo[counta -1] = item;
}
void RemoveTail()
{
  --counta;
}

void Trim()
{
  resize(counta);
  
}

void resize(size_t newCapacity)
{
  int* newList = new int[newCapacity];
  memmove(newList, datostiempo, counta * sizeof(int));
  delete[] datostiempo;
  capacity = newCapacity;
  datostiempo = newList;
}

void PrintList()
{
  Serial.print("Datos Tiempos: ");
  for (size_t index = 0; index < counta; index++)
  {
    Serial.print(datostiempo[index]);
    Serial.print(' ');
  }
  Serial.println();

}


/////////////////////////////////////////////////////////////////////////////////////////////////////////////////////////////////////////
/////////////////////////////////////////////////////////////TEMPORIZADOR///////////////////////////////////////////////////////////////////
///////////////////////////////////////////////////////////////////////////////////////////////////////////////////////////////////////////



void funcion_tempo(TimerHandle_t xTimerID)
{
  (void) xTimerID;
   Serial.println("TIEMPO------------------------");
   if(estado == 4)
   {
    salir_estado4 = true;
    estado = 5;
   }
    Serial.println("Parar temporizador");
  
}



//////////////////////////////////////////////////////////////////////////////////////////////////////////////////////////////////////////////////////////////////////////////////////
//////////////////////////////////////////////////////////////////////////////////////////BLUETOOTH///////////////////////////////////////////////////////////////////////////////////
//////////////////////////////////////////////////////////////////////////////////////////////////////////////////////////////////////////////////////////////////////////////////////
void conexion_callback(uint16_t conn_handle)
{
  Serial.println("Conectado");
  Bluefruit.Advertising.stop();
  BLEConnection* connection = Bluefruit.Connection(conn_handle);
  
  if(estado == 1)
  {
    salir_ble = true;
    estado = 2;
  }
  
  if(estado == 5)
  {
    delay(3000);
    convertir_datos();
    Serial.print("Datos enviados: ");
    Serial.println(datos2);
    bleuart.write(datos2);
    
    
  }
  
}

void desconexion_callback(uint16_t conn_handle, uint8_t reason)
{
  (void) conn_handle;
  (void) reason;
  Serial.println("Desconectado del maestro");
  if(estado == 2)
  {
    salir_recibirdato = true;
    estado = 3;
  }
  if(estado == 5)
  {
    salir_ble1 = true;
    estado = 6;
  }
}

void bleuart_rx_callback(uint16_t conn_hdl)
{
  (void) conn_hdl;
  Serial.println("Recibiendo datos...");
  uint8_t* prueba;
  while(bleuart.available())
  {
    *prueba = bleuart.read();
    temporizador = *prueba;
    Serial.print("El dato recibido es: ");
    Serial.println(temporizador);
    if (temporizador != 0)
    {
      break;
    }
  }
}
void startAdv()
{
  Bluefruit.Advertising.addFlags(BLE_GAP_ADV_FLAGS_LE_ONLY_GENERAL_DISC_MODE);
  Bluefruit.Advertising.addTxPower(); //Se añade la potencia que tendra el paquete de Advertising
  Bluefruit.Advertising.addService(bleuart); //Se añade el servicio al paquete de advertising
  Bluefruit.ScanResponse.addName(); //Se añade el nombre al proceso de advertising
  Bluefruit.Advertising.restartOnDisconnect(true);  //Se activa el auto advertising en caso de desconexion
  Bluefruit.Advertising.setInterval(32, 244); //Se configura el intervalo del advertising
  Bluefruit.Advertising.setFastTimeout(30); 
  Bluefruit.Advertising.start(0); //0 significa que no para de realizar el advertising despues de n segundos. 
  Serial.println("Advertising...");
  
}


void config_ble()
{
 
  Bluefruit.autoConnLed(false); //Se desconecta el led de conexion
  Bluefruit.configPrphBandwidth(BANDWIDTH_MAX); //Se configura el periferico con el maximo ancho de banda
  Bluefruit.begin(); //Comienza la configuracion de BLE
  Bluefruit.setTxPower(4);  //Se configura la potencia de transmision a 4 
  Bluefruit.setName("Nodo1"); //Se configura el nombre con el que se mostrara
  bleuart.setRxCallback(bleuart_rx_callback);
  Bluefruit.Periph.setConnectCallback(conexion_callback); //Se indica la funcion a la que se ira el programa cuando se realice la conexion
  Bluefruit.Periph.setDisconnectCallback(desconexion_callback);//Se indica la funcion a la que se ira el programa cuando se realice la desconexion.
  bleuart.begin(); //Comienza el servicio de BleUart.
  Serial.println("BLE configurado");
  startAdv(); //Comienza el proceso de advertising.
}

void enviar_datos_ble()
{
  delay(3000);
  convertir_datos();
  bleuart.print(datos2);
  Serial.print("Datos enviados: ");
  Serial.println(datos2);
}
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
